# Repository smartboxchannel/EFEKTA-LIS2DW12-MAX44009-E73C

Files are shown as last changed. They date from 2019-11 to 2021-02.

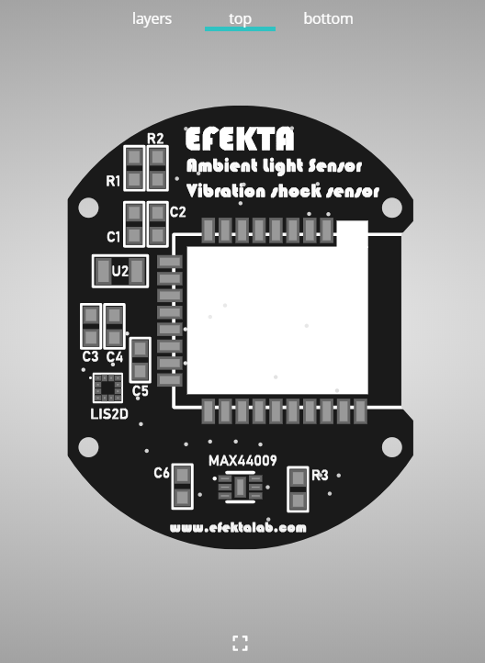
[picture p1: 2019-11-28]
IMAGES/V1.3_TOP.png

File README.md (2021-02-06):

# EFEKTA-LIS2DW12-OR-LIS2DH12-MAX44009-E73C

Light sensor(LUX) and vibration.

#### Don't donate to me, it doesn't work in this world: https://paypal.me/efektalab , just buy:

Contact: altigraph@yandex.com

Video: https://youtu.be/I2ywIxp-RsE

More info at http://efektalab.com/lima52 (still not working)

---

---

### Components (see also BOM.CSV):

1. a. nRF 52840 E73-2G4M08S1C (U1) - https://ali.ski/Bc8_x

OR

1. b. nRF 52840 E73-2G4M08S1C (U1) - https://ali.ski/3p2PEK

OR

1. c. nRF 52840 E73-2G4M08S1C (U1) - https://ali.ski/c9UlL

2. FC-135 3215 3.2*1.5 32.768KHZ Resonator (U2) - https://ali.ski/PKZVq8

3. a. LIS2DW12 (U3) - https://ali.ski/z_OaK

OR

3. b. LIS2DH12 (U3) - https://ali.ski/dxZY1

4. MAX44009EDT (U3) - https://ali.ski/vQTH8c

5. Micro Button Tact Switch SMD 4Pin 3X4X2.5MM White (U5, U6) - https://ali.ski/9t2Axp

6. BROWN Battery Button Cell Holder Socket Case Black TBH-CR2032-15K (U7) - https://ali.ski/z2RbRj

7. 2x3P | 6pin | 1.27mm | SMT | Pin Header Female (U8) - http://ali.ski/tKqX1J

8. 1210 Capacitor 100UF 10V (C7) - https://ali.ski/hRCu5

9. 0603 SMD 1/8W chip resistor 5.6K (R1, R2) - https://ali.ski/8WIRx

10. 0603 SMD 1/8W chip resistor 10K (R3, R5, R7) - https://ali.ski/8WIRx

11. 0603 SMD 1/8W chip resistor 15K (R4) - https://ali.ski/8WIRx

12. 0603 SMD 1/8W chip resistor 5K (R6) - https://ali.ski/8WIRx

13. Capacitor 12PF 0603 (C1, C2) - https://ali.ski/KMz2x

14. Capacitor 100NF 0603 (C3, C5, C6) - https://ali.ski/KMz2x

15. Capacitor 10UF 0603 (C4) - https://ali.ski/KMz2x

16. RGB LED | SMD 0805 | RGBL | RGB LED - http://ali.ski/BPc4y

---

17. M1.4 4mm Round Head Micro Screws(2) - http://ali.ski/sV_W2

18. M1.4 5mm Round Head Micro Screws(2) - http://ali.ski/sV_W2

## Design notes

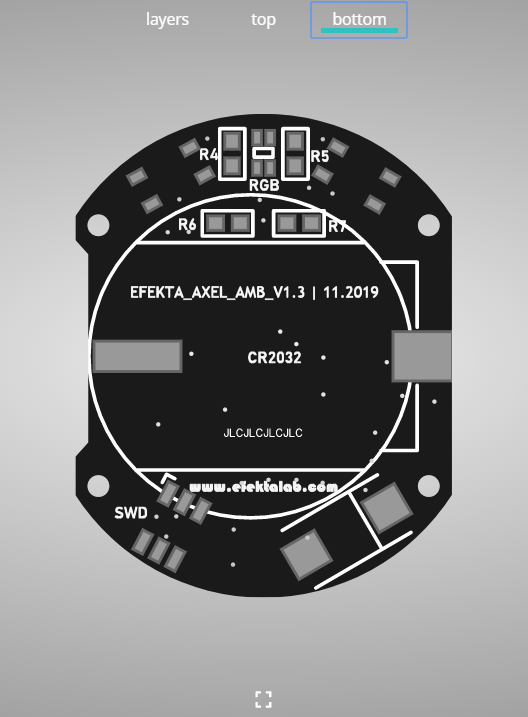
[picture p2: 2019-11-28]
IMAGES/V1.3_BOTTOM.png

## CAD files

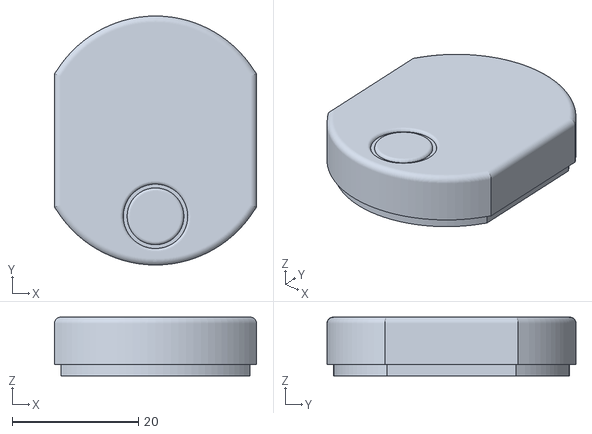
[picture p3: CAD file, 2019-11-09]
CASE/two_sla.STL
32.0 x 39.4 x 9.30

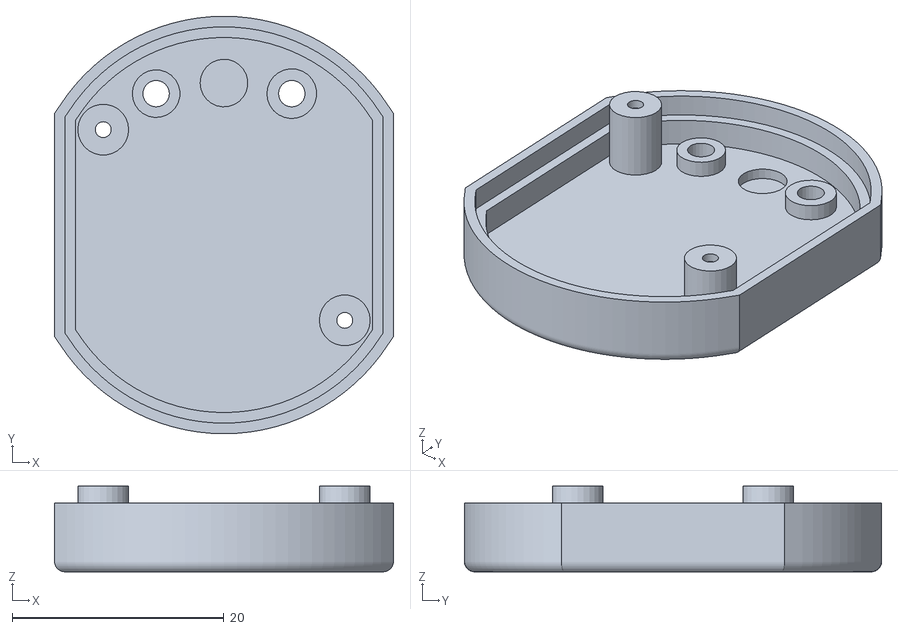
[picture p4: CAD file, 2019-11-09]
CASE/one_uni.STL
32.0 x 39.4 x 8.10

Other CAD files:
CASE/two_fdm.STL

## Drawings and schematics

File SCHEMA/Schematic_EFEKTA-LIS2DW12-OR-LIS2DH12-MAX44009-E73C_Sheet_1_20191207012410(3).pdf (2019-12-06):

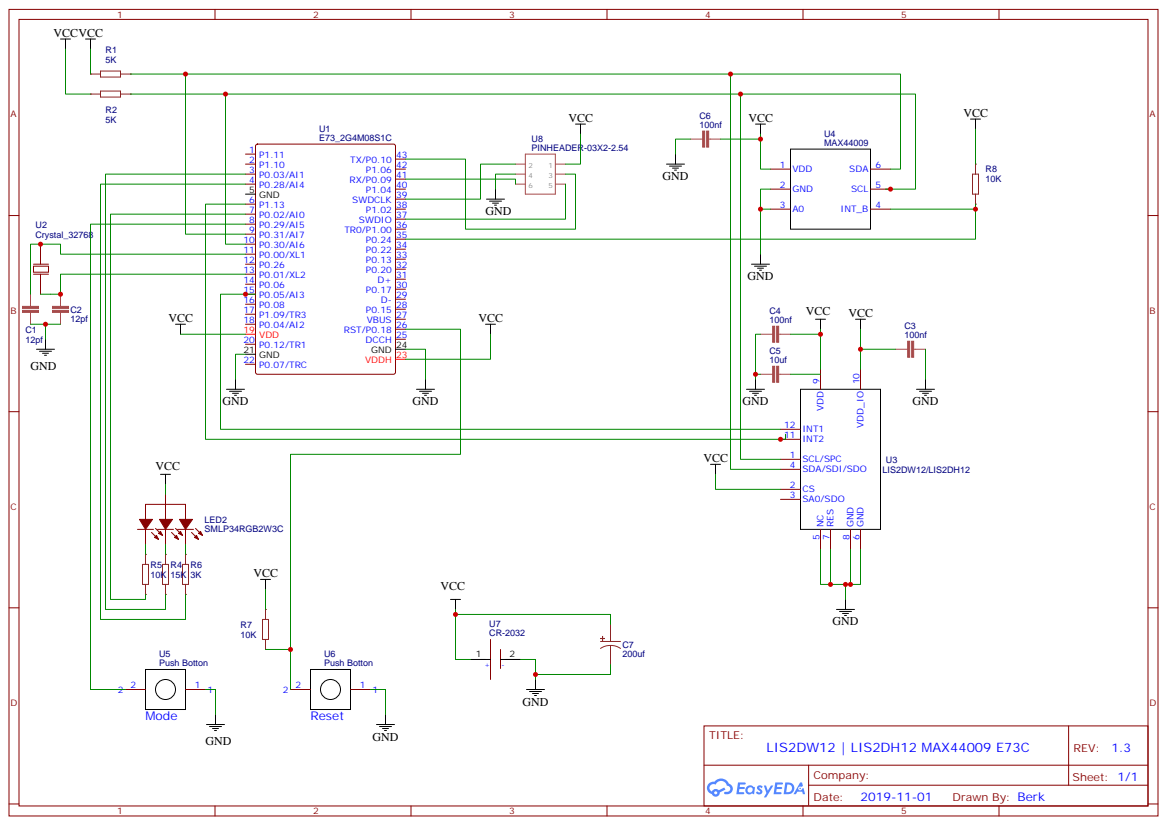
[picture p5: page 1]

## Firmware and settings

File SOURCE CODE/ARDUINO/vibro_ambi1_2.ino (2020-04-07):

// SDK PORT
extern "C" {
#include "app_gpiote.h"
#include "nrf_gpio.h"
}
#define APP_GPIOTE_MAX_USERS 1
#include <LIS2DW12Sensor.h>
#include <MAX44009.h>
//#define MY_DEBUG
#define MY_RADIO_NRF5_ESB
#define MY_DISABLED_SERIAL
int16_t mtwr;
#define MY_TRANSPORT_WAIT_READY_MS (mtwr)
#define MY_NRF5_ESB_PA_LEVEL (NRF5_PA_MAX)
#include <MySensors.h>
#define SN "LUX & SHOCK SENS"
#define SV "2.1"
#define V_SENS_CHILD_ID 1
#define LUX_SENS_CHILD_ID 2
#define WPM_SENS_CHILD_ID 3
#define INTERVAL_R_LUX_CHILD_ID 220
#define LEVEL_SENSIV_V_SENS_CHILD_ID 230
#define ENABLE_WPM_SENS_CHILD_ID 240
#define SIGNAL_Q_ID 253

#include <MySensors.h>
MyMessage vibroMsg(V_SENS_CHILD_ID, V_TRIPPED);
MyMessage brightMsg(LUX_SENS_CHILD_ID, V_LEVEL);
MyMessage wpmMsg(WPM_SENS_CHILD_ID, V_LEVEL);
MyMessage conf_wpmMsg(ENABLE_WPM_SENS_CHILD_ID, V_VAR1);
MyMessage conf_vsensMsg(LEVEL_SENSIV_V_SENS_CHILD_ID, V_VAR1);
MyMessage conf_interv_rluxMsg(INTERVAL_R_LUX_CHILD_ID, V_VAR1);

bool sendOk;
bool nosleep = 0;
bool button_flag = 0;
bool configMode = 0;
bool wpm_enable = 0;
bool onoff = 1;
bool flag_update_transport_param;
bool flag_sendRoute_parent;
bool flag_no_present;
bool flag_nogateway_mode;
bool flag_find_parent_process;
bool flag_fcount;
bool Ack_TL;
bool Ack_FP;
bool PRESENT_ACK;
byte conf_vibro_set = 1;
byte interval_reading_lux = 10;
byte err_delivery_beat;
byte problem_mode_count;
uint8_t  countbatt = 0;
uint8_t batt_cap;
uint8_t old_batt_cap = 100;
//unsigned long BATT_TIME = 43200000; //12 hours
uint32_t BATT_TIME = 7200000; //12 hours
uint32_t SLEEP_TIME_TEMP = 60000; //1 minute
uint32_t SLEEP_TIME;
uint32_t C_BATT_TIME;
uint32_t oldmillis;
uint32_t newmillis;
uint32_t previousMillis;
uint32_t lightMillisR;
uint32_t configMillis;
uint32_t interrupt_time;
uint32_t SLEEP_TIME_W;
uint32_t axel_time;
int16_t result;
int16_t brightness;
int16_t lastbrightness;
int16_t brightThreshold = 25;
int16_t myid;
int16_t mypar;
int16_t old_mypar = -1;
int16_t master_id;
float Wpm;
float ODR_1Hz6_LP_ONLY = 1.6f;
float ODR_12Hz5 = 12.5f;
float ODR_25Hz = 25.0f;
float ODR_50Hz = 50.0f;
float ODR_100Hz = 100.0f;
float ODR_200Hz = 200.0f;
bool vibro = 1;
static app_gpiote_user_id_t m_gpiote_user_id;
uint32_t PIN_BUTTON1_MASK;
uint32_t AXEL_INT1_MASK;
volatile byte axelInt1Status = 0;
volatile byte buttInt1Status = 0;
uint16_t batteryVoltage;
int16_t linkQuality;
int16_t old_linkQuality;
LIS2DW12Sensor *lis2;
MAX44009 light;



void preHwInit() {
  board_Init();
}



void before() {
  blinky(1, 1, GREEN_LED);
  wait(1000);
  nRF_Init();
  device_Conf();
  happy_init();
}



void setup() {
  interrupt_Init();
  sensors_Init();
  config_Happy_node();
}



void presentation()
{
  sendOk = sendSketchInfo(SN, SV);
  if (sendOk == false) {
    _transportSM.failedUplinkTransmissions = 0;
    wait(20);
    sendOk = sendSketchInfo(SN, SV);
    wait(20);
    if (sendOk == false) {
      wait(40);
      _transportSM.failedUplinkTransmissions = 0;
      sendOk = sendSketchInfo(SN, SV);
      wait(40);
    }
  }

  sendOk = present(V_SENS_CHILD_ID, S_VIBRATION, "STATUS VIBRO");
  if (sendOk == false) {
    _transportSM.failedUplinkTransmissions = 0;
    wait(30);
    sendOk = present(V_SENS_CHILD_ID, S_VIBRATION, "STATUS VIBRO");
    wait(30);
    if (sendOk == false) {
      wait(60);
      _transportSM.failedUplinkTransmissions = 0;
      sendOk = present(V_SENS_CHILD_ID, S_VIBRATION, "STATUS VIBRO");
      wait(60);
    }
  }


  sendOk = present(LUX_SENS_CHILD_ID, S_LIGHT_LEVEL, "LUX");
  if (sendOk == false) {
    _transportSM.failedUplinkTransmissions = 0;
    wait(40);
    sendOk = present(LUX_SENS_CHILD_ID, S_LIGHT_LEVEL, "LUX");
    wait(40);
    if (sendOk == false) {
      wait(80);
      _transportSM.failedUplinkTransmissions = 0;
      sendOk = present(LUX_SENS_CHILD_ID, S_LIGHT_LEVEL, "LUX");
      wait(80);
    }
  }


  sendOk = present(WPM_SENS_CHILD_ID, S_LIGHT_LEVEL, "W/M^2");
  if (sendOk == false) {
    _transportSM.failedUplinkTransmissions = 0;
    wait(50);
    sendOk = present(WPM_SENS_CHILD_ID, S_LIGHT_LEVEL, "W/M^2");
    wait(50);
    if (sendOk == false) {
      wait(100);
      _transportSM.failedUplinkTransmissions = 0;
      sendOk = present(WPM_SENS_CHILD_ID, S_LIGHT_LEVEL, "W/M^2");
      wait(100);
    }
  }


  sendOk = present(SIGNAL_Q_ID, S_CUSTOM, "SIGNAL QUALITY");
  if (sendOk == false) {
    _transportSM.failedUplinkTransmissions = 0;
    wait(60);
    sendOk = present(SIGNAL_Q_ID, S_CUSTOM, "SIGNAL QUALITY");
    wait(60);
    if (sendOk == false) {
      wait(120);
      _transportSM.failedUplinkTransmissions = 0;
      sendOk = present(SIGNAL_Q_ID, S_CUSTOM, "SIGNAL QUALITY");
      wait(120);
    }
  }


  sendOk = present(ENABLE_WPM_SENS_CHILD_ID, S_CUSTOM, "ON|OFF WPM");
  if (sendOk == false) {
    _transportSM.failedUplinkTransmissions = 0;
    wait(60);
    sendOk = present(ENABLE_WPM_SENS_CHILD_ID, S_CUSTOM, "ON|OFF WPM");
    wait(60);
    if (sendOk == false) {
      wait(120);
      _transportSM.failedUplinkTransmissions = 0;
      sendOk = present(ENABLE_WPM_SENS_CHILD_ID, S_CUSTOM, "ON|OFF WPM");
      wait(120);
    }
  }


  sendOk = present(LEVEL_SENSIV_V_SENS_CHILD_ID, S_CUSTOM, "SENS LEVEL VIBRO");
  if (sendOk == false) {
    _transportSM.failedUplinkTransmissions = 0;
    wait(70);
    sendOk = present(LEVEL_SENSIV_V_SENS_CHILD_ID, S_CUSTOM, "SENS LEVEL VIBRO");
    wait(70);
    if (sendOk == false) {
      wait(140);
      _transportSM.failedUplinkTransmissions = 0;
      sendOk = present(LEVEL_SENSIV_V_SENS_CHILD_ID, S_CUSTOM, "SENS LEVEL VIBRO");
      wait(140);
    }
  }


  sendOk = present(INTERVAL_R_LUX_CHILD_ID, S_CUSTOM, "INTERVAL RLUX|MIN");
  if (sendOk == false) {
    _transportSM.failedUplinkTransmissions = 0;
    wait(80);
    sendOk = present(INTERVAL_R_LUX_CHILD_ID, S_CUSTOM, "INTERVAL RLUX|MIN");
    wait(80);
    if (sendOk == false) {
      wait(160);
      _transportSM.failedUplinkTransmissions = 0;
      sendOk = present(INTERVAL_R_LUX_CHILD_ID, S_CUSTOM, "INTERVAL RLUX|MIN");
      wait(160);
    }
  }


  sendOk = send(conf_wpmMsg.set(wpm_enable));
  if (sendOk == false) {
    _transportSM.failedUplinkTransmissions = 0;
    wait(90);
    sendOk = send(conf_wpmMsg.set(wpm_enable));
    wait(90);
    if (sendOk == false) {
      wait(180);
      _transportSM.failedUplinkTransmissions = 0;
      sendOk = send(conf_wpmMsg.set(wpm_enable));
      wait(180);
    }
  }


  sendOk = send(conf_vsensMsg.set(conf_vibro_set));
  if (sendOk == false) {
    _transportSM.failedUplinkTransmissions = 0;
    wait(100);
    sendOk = send(conf_vsensMsg.set(conf_vibro_set));
    wait(100);
    if (sendOk == false) {
      wait(200);
      _transportSM.failedUplinkTransmissions = 0;
      sendOk = send(conf_vsensMsg.set(conf_vibro_set));
      wait(200);
    }
  }


  sendOk = send(conf_interv_rluxMsg.set(interval_reading_lux));
  if (sendOk == false) {
    _transportSM.failedUplinkTransmissions = 0;
    wait(110);
    sendOk = send(conf_interv_rluxMsg.set(interval_reading_lux));
    wait(110);
    if (sendOk == false) {
      wait(220);
      _transportSM.failedUplinkTransmissions = 0;
      sendOk = send(conf_interv_rluxMsg.set(interval_reading_lux));
      wait(220);
    }
  }

}



void loop()
{
  if (flag_update_transport_param == 1) {
    update_Happy_transport();
  }
  if (flag_sendRoute_parent == 1) {
    present_only_parent();
  }

  if (isTransportReady() == true) {
    if (flag_nogateway_mode == 0) {
      if (flag_find_parent_process == 1) {
        find_parent_process();
      }
      if (configMode == 0) {
        if ((axelInt1Status == AXEL_INT1) || (buttInt1Status == PIN_BUTTON1)) {
          if (axelInt1Status == AXEL_INT1) {
            nosleep = 1;
            send_Axel();
            axelInt1Status = 0;
            newmillis = millis();
            interrupt_time = newmillis - oldmillis;
            SLEEP_TIME_W = SLEEP_TIME_W - interrupt_time;
            if (SLEEP_TIME_W < 5000) {
              SLEEP_TIME_W = SLEEP_TIME;
              send_Brigh(1);
              countbatt++;
              if (countbatt == C_BATT_TIME) {
                sendBatteryStatus(1);
                countbatt = 0;
              }
            }
            nosleep = 0;
          }
          if (buttInt1Status == PIN_BUTTON1) {
            if (digitalRead(PIN_BUTTON1) == 0 && button_flag == 0) {
              button_flag = 1;
              nosleep = 1;
              previousMillis = millis();
              ledsOff();
            }
            if (digitalRead(PIN_BUTTON1) == 0 && button_flag == 1) {
              if ((millis() - previousMillis > 0) && (millis() - previousMillis <= 1750)) {
                if (millis() - lightMillisR > 25) {
                  lightMillisR = millis();
                  onoff = !onoff;
                  digitalWrite(GREEN_LED, onoff);
                }
              }
              if ((millis() - previousMillis > 1750) && (millis() - previousMillis <= 2000)) {
                ledsOff();
              }
              if ((millis() - previousMillis > 2000) && (millis() - previousMillis <= 4000)) {
                if (millis() - lightMillisR > 25) {
                  lightMillisR = millis();
                  onoff = !onoff;
                  digitalWrite(BLUE_LED, onoff);
                }
              }
              if ((millis() - previousMillis > 4000) && (millis() - previousMillis <= 4250)) {
                ledsOff();
              }
              if ((millis() - previousMillis > 4250) && (millis() - previousMillis <= 6250)) {
                if (millis() - lightMillisR > 25)    {
                  lightMillisR = millis();
                  onoff = !onoff;
                  digitalWrite(RED_LED, onoff);
                }
              }
              if ((millis() - previousMillis > 6250) && (millis() - previousMillis <= 6500)) {
                ledsOff();
              }
              if ((millis() - previousMillis > 6500) && (millis() - previousMillis <= 8500)) {
                if (millis() - lightMillisR > 50)    {
                  lightMillisR = millis();
                  onoff = !onoff;
                  digitalWrite(RED_LED, onoff);
                }
              }
              if (millis() - previousMillis > 8500) {
                ledsOff();
              }
            }
            if (digitalRead(PIN_BUTTON1) == 1 && button_flag == 1) {
              if (millis() - previousMillis <= 2000)
              {
                ledsOff();
                send_Brigh(0);
                nosleep = 0;
                button_flag = 0;
                buttInt1Status = 0;
              }
              if ((millis() - previousMillis > 2000) && (millis() - previousMillis <= 4000))
              {
                ledsOff();
                configMode = 1;
                button_flag = 0;
                configMillis = millis();
              }
              if ((millis() - previousMillis > 4250) && (millis() - previousMillis <= 6250))
              {
                ledsOff();
                blinky(2, 2, RED_LED);
                button_flag = 0;
                buttInt1Status = 0;
                presentation();
                nosleep = 0;
              }
              if ((millis() - previousMillis > 6500) && (millis() - previousMillis <= 8500))
              {
                ledsOff();
                blinky(3, 3, RED_LED);
                new_device();
              }
              if (((millis() - previousMillis > 1750) && (millis() - previousMillis <= 2000)) || ((millis() - previousMillis > 4000) && (millis() - previousMillis <= 4250)) || ((millis() - previousMillis > 6250) && (millis() - previousMillis <= 6500)) || ((millis() - previousMillis > 8500)))
              {
                ledsOff();
                blinky(1, 2, GREEN_LED);
                nosleep = 0;
                button_flag = 0;
                buttInt1Status = 0;
              }
            }
          }
        } else {
          SLEEP_TIME_W = SLEEP_TIME;
          send_Brigh(1);
          countbatt++;
          if (countbatt == C_BATT_TIME) {
            sendBatteryStatus(1);
            countbatt = 0;
          }
          nosleep = 0;
        }
      } else {
        if (millis() - configMillis > 30000) {
          blinky(3, 3, GREEN_LED);
          configMode = 0;
          nosleep = 0;
          button_flag = 0;
          buttInt1Status = 0;
        }
      }
    } else {
      if (buttInt1Status == PIN_BUTTON1) {

        if (digitalRead(PIN_BUTTON1) == 0 && button_flag == 0) {
          button_flag = 1;
          nosleep = 1;
          previousMillis = millis();
          ledsOff();
        }

        if (digitalRead(PIN_BUTTON1) == 0 && button_flag == 1) {
          if ((millis() - previousMillis > 0) && (millis() - previousMillis <= 500))
          {
            ledsOff();
          }
          if ((millis() - previousMillis > 500) && (millis() - previousMillis <= 2500))
          {
            lightMillisR = millis();
            onoff = !onoff;
            digitalWrite(BLUE_LED, onoff);
          }
          if ((millis() - previousMillis > 2500) && (millis() - previousMillis <= 2750))
          {
            ledsOff();
          }
          if ((millis() - previousMillis > 2750) && (millis() - previousMillis <= 4750)) {
            if (millis() - lightMillisR > 50) {
              lightMillisR = millis();
              onoff = !onoff;
              digitalWrite(RED_LED, onoff);
            }
          }

          if (millis() - previousMillis > 4750) {
            ledsOff();
            blinky(3, 1, GREEN_LED);
            button_flag = 0;
            nosleep = 0;
            buttInt1Status = 0;
          }
        }

        if (digitalRead(PIN_BUTTON1) == 1 && button_flag == 1) {
          if (millis() - previousMillis <= 500)
          {
            ledsOff();
            button_flag = 0;
            nosleep = 0;
            buttInt1Status = 0;
          }
          if ((millis() - previousMillis > 500) && (millis() - previousMillis <= 2500))
          {
            ledsOff();
            blinky(1, 1, BLUE_LED);
            check_parent();
            button_flag = 0;
            nosleep = 0;
            buttInt1Status = 0;
          }

          if ((millis() - previousMillis > 2500) && (millis() - previousMillis <= 2750))
          {
            ledsOff();
            button_flag = 0;
            nosleep = 0;
            buttInt1Status = 0;
          }

          if ((millis() - previousMillis > 2750) && (millis() - previousMillis <= 4750))
          {
            ledsOff();
            blinky(3, 3, RED_LED);
            new_device();
          }

          if (millis() - previousMillis > 4750)
          {
            ledsOff();
            button_flag = 0;
            nosleep = 0;
            buttInt1Status = 0;
          }
        }
      } else {
        check_parent();
      }
    }
  }

  if (_transportSM.failureCounter > 0)
  {
    _transportConfig.parentNodeId = loadState(101);
    _transportConfig.nodeId = myid;
    _transportConfig.distanceGW = loadState(103);
    mypar = _transportConfig.parentNodeId;
    nosleep = 0;
    flag_fcount = 1;
    err_delivery_beat = 5;
    happy_node_mode();
    gateway_fail();
  }

  if (configMode == 0) {
    if (nosleep == 0) {
      oldmillis = millis();
      axelInt1Status = 0;
      buttInt1Status = 0;
      wait(100);
      sleep(SLEEP_TIME_W, false);
      wait(50);
      nosleep = 1;
    }
  }
}



float GetWpm()
{
  float SunLuxCoef = 0.0079;
  float Wpm_temp = 0;
  Wpm_temp = (float)brightness;
  Wpm_temp *= SunLuxCoef;
  return Wpm_temp;
}



void blinky(uint8_t pulses, uint8_t repit, uint8_t ledColor) {
  for (int x = 0; x < repit; x++) {
    if (x > 0) {
      sleep(300);
    }
    for (int i = 0; i < pulses; i++) {
      if (i > 0) {
        sleep(80);
      }
      digitalWrite(ledColor, LOW);
      sleep(20);
      digitalWrite(ledColor, HIGH);
    }
  }
}



void ledsOff() {
  digitalWrite(RED_LED, HIGH);
  digitalWrite(GREEN_LED, HIGH);
  digitalWrite(BLUE_LED, HIGH);
}



void nRF_Init() {
  NRF_POWER->DCDCEN = 1;
  NRF_NFCT->TASKS_DISABLE = 1;
  NRF_NVMC->CONFIG = 1;
  NRF_UICR->NFCPINS = 0;
  NRF_NVMC->CONFIG = 0;
  NRF_SAADC ->ENABLE = 0;
  NRF_PWM0  ->ENABLE = 0;
  NRF_PWM1  ->ENABLE = 0;
  NRF_PWM2  ->ENABLE = 0;
  NRF_TWIM1 ->ENABLE = 0;
  NRF_TWIS1 ->ENABLE = 0;
  NRF_RADIO->TXPOWER = 8;
}



void sensors_Init() {
  Wire.begin();
  wait(100);
  light.begin();
  wait(100);
  lis2 = new LIS2DW12Sensor (&Wire);
  vibro_Init();
  if (isTransportReady() == true) {
    blinky(3, 1, BLUE_LED);
    wait(200);
    blinky(3, 1, GREEN_LED);
    wait(200);
    blinky(3, 1, RED_LED);
    SLEEP_TIME_W = SLEEP_TIME;
    send_Brigh(0);
    wait(50);
    sendBatteryStatus(0);
    axel_time = millis();
  } else {
    blinky(5, 3, RED_LED);
  }
}



void vibro_Init() {
  if (conf_vibro_set == 1) {
    lis2->ODRTEMP = ODR_1Hz6_LP_ONLY;
  }
  if (conf_vibro_set == 2) {
    lis2->ODRTEMP = ODR_12Hz5;
  }
  if (conf_vibro_set == 3) {
    lis2->ODRTEMP = ODR_25Hz;
  }
  if (conf_vibro_set == 4) {
    lis2->ODRTEMP = ODR_100Hz;
  }
  if (conf_vibro_set == 5) {
    lis2->ODRTEMP = ODR_200Hz;
  }
  lis2->Enable_X();
  wait(50);
  lis2->Enable_Wake_Up_Detection();
  wait(50);
}



void board_Init() {
  pinMode(PIN_BUTTON1, INPUT);
  pinMode(AXEL_INT1, INPUT);
  pinMode(AXEL_INT2, INPUT);
  pinMode(AMBI_INT, INPUT);
  pinMode(RED_LED, OUTPUT);
  pinMode(GREEN_LED, OUTPUT);
  pinMode(BLUE_LED, OUTPUT);
  ledsOff();
}



void send_Axel() {
  if (millis() - axel_time >= 5000) {
    blinky(6, 1, RED_LED);
    lis2->Disable_Wake_Up_Detection();
    wait(100);
    sendOk = send(vibroMsg.set(vibro));
    if (sendOk == false) {
      _transportSM.failedUplinkTransmissions = 0;
      wait(30);
      sendOk = send(vibroMsg.set(vibro));
      wait(30);
      if (sendOk == false) {
        wait(60);
        _transportSM.failedUplinkTransmissions = 0;
        sendOk = send(vibroMsg.set(vibro));
        wait(60);
      }
    }
    if (sendOk == true) {
      err_delivery_beat = 0;
      if (flag_nogateway_mode == 1) {
        flag_nogateway_mode = 0;
        CORE_DEBUG(PSTR("MyS: NORMAL GATEWAY MODE\n"));
        err_delivery_beat = 0;
      }
    } else {
      _transportSM.failedUplinkTransmissions = 0;
      if (err_delivery_beat < 5) {
        err_delivery_beat++;
      }
      if (err_delivery_beat == 4) {
        if (flag_nogateway_mode == 0) {
          gateway_fail();
          CORE_DEBUG(PSTR("MyS: LOST GATEWAY MODE\n"));
        }
      }
    }
    lis2->Enable_Wake_Up_Detection();
    wait(100);
    axel_time = millis();
    nosleep = 0;
  } else {
    nosleep = 0;
  }
}



void send_Brigh(bool start) {
  brightness = light.get_lux() * 2;
  wait(50);
  if (start == 1) {
    if (abs(brightness - lastbrightness) >= brightThreshold) {
      sendOk = send(brightMsg.set(brightness, 0));
      if (sendOk == false) {
        _transportSM.failedUplinkTransmissions = 0;
        wait(30);
        sendOk = send(brightMsg.set(brightness, 0));
        wait(30);
        if (sendOk == false) {
          wait(60);
          _transportSM.failedUplinkTransmissions = 0;
          sendOk = send(brightMsg.set(brightness, 0));
          wait(60);
        }
      }
      if (sendOk == true) {
        err_delivery_beat = 0;
        if (flag_nogateway_mode == 1) {
          flag_nogateway_mode = 0;
          CORE_DEBUG(PSTR("MyS: NORMAL GATEWAY MODE\n"));
          err_delivery_beat = 0;
        }
        lastbrightness = brightness;
        if (wpm_enable == 1) {
          Wpm = GetWpm();
          wait(100);
          send(wpmMsg.set(Wpm, 0));
        }
        wait(50);
        blinky(2, 2, BLUE_LED);
      } else {
        _transportSM.failedUplinkTransmissions = 0;
        if (err_delivery_beat < 5) {
          err_delivery_beat++;
        }
        if (err_delivery_beat == 4) {
          if (flag_nogateway_mode == 0) {
            gateway_fail();
            CORE_DEBUG(PSTR("MyS: LOST GATEWAY MODE\n"));
          }
        }
      }
    }
  } else {
    sendOk = send(brightMsg.set(brightness, 0));
    if (sendOk == false) {
      _transportSM.failedUplinkTransmissions = 0;
      wait(30);
      sendOk = send(brightMsg.set(brightness, 0));
      wait(30);
      if (sendOk == false) {
        wait(60);
        _transportSM.failedUplinkTransmissions = 0;
        sendOk = send(brightMsg.set(brightness, 0));
        wait(60);
      }
    }
    lastbrightness = brightness;
    if (wpm_enable == 1) {
      Wpm = GetWpm();
      sendOk = send(wpmMsg.set(Wpm, 0));
      if (sendOk == false) {
        _transportSM.failedUplinkTransmissions = 0;
        wait(30);
        sendOk = send(wpmMsg.set(Wpm, 0));
        wait(30);
        if (sendOk == false) {
          wait(60);
          _transportSM.failedUplinkTransmissions = 0;
          sendOk = send(wpmMsg.set(Wpm, 0));
          wait(60);
        }
      }
    }
    blinky(2, 2, BLUE_LED);
  }
}



void interrupt_Init() {
  //***
  //SET
  //NRF_GPIO_PIN_NOPULL
  //NRF_GPIO_PIN_PULLUP
  //NRF_GPIO_PIN_PULLDOWN
  //***
  nrf_gpio_cfg_input(PIN_BUTTON1, NRF_GPIO_PIN_PULLUP);
  nrf_gpio_cfg_input(AXEL_INT1, NRF_GPIO_PIN_NOPULL);
  APP_GPIOTE_INIT(APP_GPIOTE_MAX_USERS);
  PIN_BUTTON1_MASK = 1 << PIN_BUTTON1;
  AXEL_INT1_MASK = 1 << AXEL_INT1;
  //  app_gpiote_user_register(p_user_id, pins_low_to_high_mask, pins_high_to_low_mask, event_handler)
  app_gpiote_user_register(&m_gpiote_user_id, AXEL_INT1_MASK, PIN_BUTTON1_MASK, gpiote_event_handler);
  app_gpiote_user_enable(m_gpiote_user_id);
  axelInt1Status = 0;
  buttInt1Status = 0;
}
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

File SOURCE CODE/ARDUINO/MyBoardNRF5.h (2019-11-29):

/*
  If you don't use an nRF5 board, you can ignore this file.

  This file was part of the "My Sensors nRF5 Boards" board repository
  available at https://github.com/mysensors/ArduinoBoards If you have
  questions, please refer the documentation at
  https://github.com/mysensors/ArduinoHwNRF5 first.

  This file is compatible with ArduinoHwNRF5 >= 0.2.0

  This file allows you to change the pins of internal hardware, like the
  serial port, SPI bus or Wire bus.

  All pins referenced here are mapped via the "g_ADigitalPinMap" Array
  defined in "MyBoardNRF5.cpp" to pins of the MCU.
  
  As an example, if you have at the third position in "g_ADigitalPinMap" the
  12, then all ports referenced in Arduino with 2 are mapped to P0.12. If you
  don't change the "g_ADigitalPinMap" Array, the Arduino pins 0..31 are
  translated to P0.00..P0..31.
   
  ###########################################################################
 
  This file is compatible with ArduinoHwNRF5 > 0.1.0
  Copyright (c) 2014-2015 Arduino LLC.  All right reserved.
  Copyright (c) 2016 Sandeep Mistry. All right reserved.
  Copyright (c) 2017 Sensnology AB. All right reserved.

  This library is free software; you can redistribute it and/or
  modify it under the terms of the GNU Lesser General Public
  License as published by the Free Software Foundation; either
  version 2.1 of the License, or (at your option) any later version.
  This library is distributed in the hope that it will be useful,
  but WITHOUT ANY WARRANTY; without even the implied warranty of
  MERCHANTABILITY or FITNESS FOR A PARTICULAR PURPOSE.
  See the GNU Lesser General Public License for more details.
  You should have received a copy of the GNU Lesser General Public
  License along with this library; if not, write to the Free Software
  Foundation, Inc., 51 Franklin St, Fifth Floor, Boston, MA  02110-1301  USA
*/

#ifndef _MYBOARDNRF5_H_
#define _MYBOARDNRF5_H_

#ifdef __cplusplus
extern "C"
{
#endif // __cplusplus

// Number of pins defined in PinDescription array
#define PINS_COUNT           (32u)
#define NUM_DIGITAL_PINS     (32u)
#define NUM_ANALOG_INPUTS    (8u)
#define NUM_ANALOG_OUTPUTS   (8u)

/* 
 *  LEDs
 *  
 *  This is optional
 *  
 *  With My Sensors, you can use
 *  hwPinMode() instead of pinMode()
 *  hwPinMode() allows to use advanced modes like OUTPUT_H0H1 to drive LEDs.
 *  https://github.com/mysensors/MySensors/blob/development/drivers/NRF5/nrf5_wiring_constants.h
 *
 */
#define PIN_LED1                (28)
#define PIN_LED2                (3)
#define PIN_LED3                (2)
// #define PIN_LED4                (27)
// #define PIN_LED5                (12)
// #define PIN_LED6                (14)
// #define PIN_LED7                (15)
// #define PIN_LED8                (16)
// #define USER_LED             	 (PIN_LED2)
#define RED_LED                (PIN_LED1)
#define GREEN_LED            	 (PIN_LED2)
#define BLUE_LED			         (PIN_LED3)
// #define BLE_LED                 BLUE_LED
// #define LED_BUILTIN          PIN_LED1

/* 
 *  Buttons
 *  
 *  This is optional
 */
#define PIN_BUTTON1             (29)
// #define PIN_BUTTON2             (4)
// #define PIN_BUTTON3             (5)
// #define PIN_BUTTON4             (6)
// #define PIN_BUTTON5             (7)
// #define PIN_BUTTON6             (8)
// #define PIN_BUTTON7             (9)
// #define PIN_BUTTON8             (10)

#define AXEL_INT1             (5)
#define AXEL_INT2             (13)
#define AMBI_INT             (24)

/* 
 * Analog ports
 *  
 * If you change g_APinDescription, replace PIN_AIN0 with
 * port numbers mapped by the g_APinDescription Array.
 * You can add PIN_AIN0 to the g_APinDescription Array if
 * you want provide analog ports MCU independed, you can add
 * PIN_AIN0..PIN_AIN7 to your custom g_APinDescription Array
 * defined in MyBoardNRF5.cpp
 */
static const uint8_t A0  = ADC_A0;
static const uint8_t A1  = ADC_A1;
static const uint8_t A2  = ADC_A2;
static const uint8_t A3  = ADC_A3;
static const uint8_t A4  = ADC_A4;
static const uint8_t A5  = ADC_A5;
static const uint8_t A6  = ADC_A6;
static const uint8_t A7  = ADC_A7;

/*
 * Serial interfaces
 * 
 * RX and TX are required.
 * If you have no serial port, use unused pins
 * CTS and RTS are optional.
 */
#define PIN_SERIAL_RX       (9)
#define PIN_SERIAL_TX       (10)
// #define PIN_SERIAL_CTS      (13)
// #define PIN_SERIAL_RTS      (14)

/*
 * SPI Interfaces
 * 
 * This is optional
 * 
 * If SPI is defined MISO, MOSI, SCK are required
 * SS is optional and can be used in your sketch.
 */
#define SPI_INTERFACES_COUNT 1

#define PIN_SPI_MISO         (15)
#define PIN_SPI_MOSI         (17)
#define PIN_SPI_SCK          (20)
#define PIN_SPI_SS           (22)

static const uint8_t SS   = PIN_SPI_SS;
static const uint8_t MOSI = PIN_SPI_MOSI;
static const uint8_t MISO = PIN_SPI_MISO;
static const uint8_t SCK  = PIN_SPI_SCK;

/*
 * Wire Interfaces
 *
 * This is optional
 */
#define WIRE_INTERFACES_COUNT 2
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

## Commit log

2019-10-26 V1.2
    add lis2dh
    [BoardOutline.gbr, BottomMask.gbr, BottomPaste.gbr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]
2019-11-09 v1.3
    removed power line on CS pin
    [BottomMask.gbr, BottomPaste.gbr, BottomSilk.gbr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]
